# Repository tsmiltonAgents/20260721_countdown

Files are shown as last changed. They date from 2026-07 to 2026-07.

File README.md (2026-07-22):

# T-MINUS — keyring countdown to 2026-10-10 12:00

A 46 × 23 mm, 4-layer keyring PCB that counts down the hours to
**10 October 2026, midday** on a red 4-digit 7-segment display. Powered by a
CR2032, it keeps time for years in deep sleep; press the button and the
hours remaining glow for 8 seconds. Under 100 hours to go it switches to
minutes (decimal point lit as the marker). At T-0 it shows `0.0.0.0`.

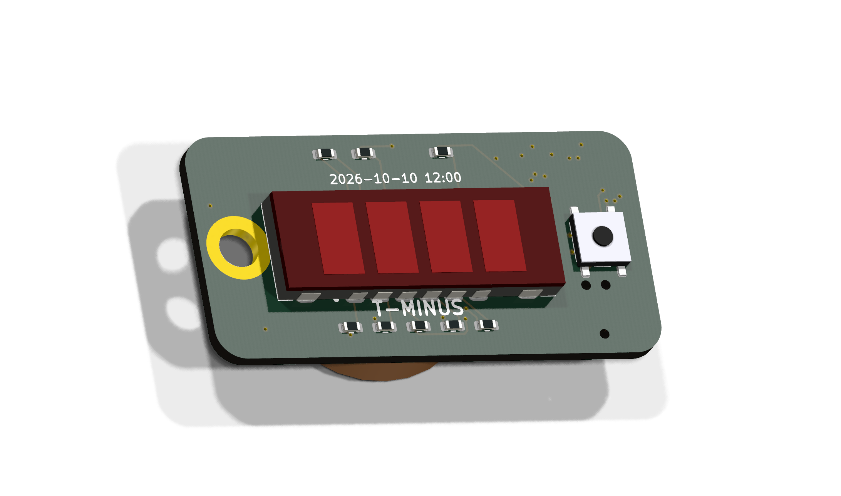
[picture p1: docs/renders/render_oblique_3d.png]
render


## How it works

- **STM32L031G6U6** (QFN28) runs the show: RTC on a 32.768 kHz crystal,
  Stop-mode sleep at ~1 µA with full RAM retention.
- **XINGLIGHT XL-SA2401SRWC** 0.2" 4-digit red display, common cathode,
  multiplexed directly from GPIO (segments through 330 Ω on PA0–PA7, digit
  cathodes on PB0/PB1/PA8/PA9). Red Vf ≈ 1.8 V runs straight off the coin
  cell — no boost, no driver IC.
- **Battery life**: ~1 µA sleeping + ~10 mA for 8 s per press. At ten
  presses/day that's ≈ 2 years on one CR2032; the countdown itself survives
  until the cell is truly dead.
- **Programming**: Tag-Connect TC2030-IDC-NL footprint (zero BOM cost). Flash
  with any SWD probe; the RTC is seeded from the firmware build timestamp,
  so `make flash` right after `make` and the clock is correct to seconds.
- Front: display, button, segment resistors. Back: CR2032 holder, MCU,
  crystal, TC2030. Keyring hole (Ø4) at the left end, clear of everything.

## Repo layout

| Path | What |
|---|---|
| `hw/countdown/` | KiCad 10 project (schematic, PCB, DRC/ERC reports) |
| `hw/lib/` | Custom symbols + footprints (display, holder, switch, hole) |
| `hw/scripts/` | The full generation pipeline (see below) |
| `fab/` | **JLCPCB order files: gerbers.zip, bom.csv, cpl.csv** |
| `fw/` | Firmware (bare-metal C, no HAL; `make && make flash`) |
| `docs/renders/` | Verification renders (incl. 3D-model views) |
| `hw/mech/` | build123d part models (via earthtojake/text-to-cad CAD skill) → STEP |
| `designlog.md` | Full engineering narrative, decisions and reviews |
| `prompts.md` | Prompt log |

## Reproducing the board from scratch

Everything is generated — schematic, footprints, placement, routing, fab
files — by scripts (KiCad 10 CLI + pcbnew Python + a custom A* router):

```sh
python3 hw/scripts/gen_footprints.py     # custom footprints from datasheet dims
python3 hw/scripts/gen_sch_countdown.py  # schematic + intended netlist
# ERC + netlist verification, then:
./hw/scripts/route_own.sh                # place, fanout power, planes, route, DRC
./hw/scripts/render_views.sh             # eyeball it
# fab outputs:
<kicad-python> hw/scripts/export_fab.py hw/countdown/countdown.kicad_pcb fab/
```

## Ordering (JLCPCB)

See `fab/ORDERING.md` for the click-by-click instructions, including the
one thing you MUST eyeball in their UI: part rotations in the placement
preview (especially U1) before paying.

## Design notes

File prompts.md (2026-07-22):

# Prompts Log

All prompts given during this project, verbatim, with timestamps.

## 2026-07-21 21:01 — Initial brief (user)

> i want to have a small pcb on my keyring with a countdown to a specific date. this key ring should countdown to the date of 10th of october 2026 midday. it can have digitial electronics and a micro and be programmable, but i want it to me nice and small and simple, a simple 7 segment display, counting down in hours or minuts to this time. it should just keep running once going so needs a battery. i am ultimately going to order the board from JLC pCB and want the gerbers and pick and place and bOM. Make sure the parts come from there and can be pick and place assembled by them. i think it;ll be cool to be a bare board, but we might also want to pot it. if you need to do ANY mechanical design use this github repo https://github.com/earthtojake/text-to-cad. As you work maintain a prompts.md with all the prompts and a designlog.md with the design process and reviews etc. Then make this folder a github repo called 20260721_countdown and commit and push regularly, at least every time you do an interesting design. i want you to make sure the PCB really works, dont do routing yourself, use an autorouter, and make it a four layer board at least to make it easy for yourself. bear in mind it being small (e.g. maybe use a quickconnect jtag programmer thing or headers or something not a usb thing, then also make it wonderful for the user and pretty. keep going until you're done, and make sure you run verification loops to check (and look using your eyes) that this all really does work and then tell me to order it. i expect to wake up tomorrow to this working, but i'd prefer rigour and to wait longer than for you to fail completing it and me to waste my money on ordering PCBs that don't work

## Agent prompts (Claude → subagents / tools)

### 2026-07-21 21:15 — Four parallel research agents launched

1. **MCU research**: "Find the best microcontroller for an ultra-low-power coin-cell (CR2032, 2.0–3.0V) countdown keyring... runs 1.8–3.6V direct, RTC on external 32.768 kHz crystal, ~1 µA deep sleep keeping time, ≥13 GPIO + SWD, LQFP32/TSSOP20/QFN28-32, IN STOCK at JLCPCB parts library, Basic/Extended status... candidates STM32L031/G031/L011, PY32F002B, CH32V003 (verify it lacks LSE)... report LCSC C-numbers, stock, price, sleep current, gotchas (BOOT0, NRST, VDDA)."
2. **Display research**: "Find a 4-digit 7-segment LED display, as SMALL as practical (digit 0.2–0.4 inch, under ~42x15mm), JLC-assemblable, SMD preferred... RED (Vf ~1.8–2.0V) REQUIRED for 2.0–3.0V coin cell, disqualify blue/white/green... report full pin map, mechanical dims, LCSC number, stock, common anode/cathode... backups: 2-digit or smallest THT 4-digit."
3. **Support parts**: "CR2032 SMD holder, 32.768 kHz 3215 crystal (report CL and load caps), small SMD tactile switch, 0402/0603 Basic passives (100nF/1uF/10uF, 150–470R, 10k), optional Schottky + P-FET, Tag-Connect TC2030-NL footprint geometry + JLC-stocked 1.27mm SWD header alternative... LCSC numbers, Basic/Extended, stock."
4. **JLC fab/assembly rules**: "4-layer capabilities (track/space, via, stackup, colors), Economic vs Standard assembly (THT? both sides? fees), exact BOM/CPL file formats and column names, KiCad→JLC rotation corrections, gerber layer requirements, min board size for ~40x20mm board."

(Full verbatim agent prompts preserved in the session; condensed here for readability.)

### 2026-07-21 22:45 — JLC CPL rotation research agent

"Research JLCPCB pick-and-place rotation conventions... QFN-28 for STM32L031
(consensus of matthewlai/Bouni/KiBot databases vs Fabrication-Toolkit),
bottom-side formula from Fabrication-Toolkit process.py source, verify JLC
placement preview exists as pre-payment safety net." → Result: +270° for QFN,
bottom = (180 − rot + offset) mod 360, preview editable before payment.

### 2026-07-21 23:58 — Independent review agents (design frozen)

1. **Electrical review**: adversarial check of netlist vs STM32L031 UFQFPN28
   pinout, SWD/TC2030 pin order, display current budget vs GPIO ratings,
   CC multiplex logic vs firmware pin map, LSE loading, blank-chip first
   flash, EXTI vector, VDDA tie, RTC math. Findings ranked
   BLOCKER/MAJOR/MINOR/NIT with evidence.
2. **Firmware review**: RM0377-level check of RCC/PWR/RTC init order,
   LSEDRV-before-LSEON, shadow register staleness after Stop wake (RSF),
   EXTI config arithmetic, BSRR patterns vs SWD pins, vector table, linker,
   freestanding-libc pitfalls, calendar math transcription, DST/timezone
   seeding, Stop-mode leakage paths.

### 2026-07-22 01:20 — Footprint + DFM review agent

3. **Footprint/DFM review**: every custom footprint re-derived from its real
   datasheet (display pad grid/pin-1, battery holder pad edges + polarity
   trap, switch land + diagonal wiring proof, keyring hole mechanics),
   stock-footprint choices (QFN no-EP association, FC-135 land), double-sided
   reflow retention math, JLC fab numbers. Outcome: footprints verified
   dimensionally correct; board-level fixes applied (GND-only vias under the
   VSS-bonded QFN die pad, via-to-via ≥0.72 mm gates, silkscreen moved off
   pads + refs hidden, display pads widened to terminal width, real-silk
   battery polarity, keyring hole upgraded to plated grounded wear ring).

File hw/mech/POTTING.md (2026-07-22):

# Potting the T-MINUS board — full both-sides encapsulation

Finished part: clear 52 × 29 × 14 mm rounded slab, display lens flush at
the front face, button in an open finger well, keyring hole cast-through,
battery sealed for life (fine: the mission ends 2026-10-10; cell budget
is ~2 years).

## Print

- `pot_mold.stl` — PETG or ASA, 0.2 mm layers, 4 perimeters, glossy bed
  face down. No supports. The cavity floor IS the front surface of your
  casting: print it on a smooth PEI/glass sheet for the best finish.
- `pot_button_plug.stl` — TPU (95A), 0.1 mm layers. One per pour (reusable).

## Resin

Water-clear, UV-stabilised **polyurethane casting resin**, low exotherm,
semi-rigid (Shore D 65-75) — e.g. Smooth-On Crystal Clear 202-class.
Epoxy works but yellows in sunlight within months. ~18 ml per casting.

## Process

1. **Flash the firmware first** (`cd fw && make flash`) — the TC2030 pads
   are buried forever. Insert a fresh CR2032, press the button, confirm
   the countdown. You should see the triple decimal-point "just seeded"
   flash on power-up.
2. Clean the board with IPA (PU hates fingerprint grease).
3. Seat the TPU plug in its floor recess. Wipe the mold with release
   spray (or paste wax, buffed).
4. Pour ~2 mm of resin. Lower the board in **display-down**, keyring hole
   over the pin, right edge onto the two level nubs. The display lens
   lands on the floor → flush window. Add a small weight (~100 g) on the
   board back so the lens stays pressed against the floor.
5. Fill slowly down the mold wall to the **groove line** (z = 14 mm).
   Pop surface bubbles with a heat-gun waft.
6. Cure per resin spec at room temperature (the display is only rated
   70 °C — no oven post-cure above 60 °C).
7. Flex the mold walls, push from the base, demold. Peel the TPU plug out
   of the button well. Trim the thin flash film over the button plunger
   (it cracks away on first press) and any edge flash with a deburr blade.

## Design notes (why it's shaped this way)

- The plug tops out 0.1 mm BELOW the switch plunger: if it pressed the
  button during the cure, the MCU would run the display for the whole
  cure and drain the sealed-in cell.
- The pin is Ø3.85 for a slip fit in the plated Ø4.0 ring; it also fixes
  board rotation (off-centre hole = only one way in). Display must face
  the FLOOR — if you can see the digits looking into the mold, it's
  upside down.
- 2° wall draft + rounded corners for demolding; thumb notches on both
  rims; fill groove marks the 14 mm casting height.

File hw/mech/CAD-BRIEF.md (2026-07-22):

# CAD brief — 3D visual models for T-MINUS board parts

Origin/units per KiCad model conventions: mm, model origin = footprint
origin on the board surface (Z=0), +Z away from the board. Cosmetic render
models (not fit/tolerance parts); dimensions from the verified datasheets
in designlog.md.

1. `xl_sa2401.step` — XINGLIGHT XL-SA2401SRWC display, origin body centre.
   Body 28.5 × 10 × 3.0: bottom 2.2 grey PBT block, top 0.8 dark-red lens
   slab. Four digit windows (4.2 × 7.4, pitch 5.55, centred) recessed 0.1
   into the lens. 12 signal pads (1.5 wide × 1.5 tall × 0.2) wrapping the
   ±Y faces on 2.54 pitch (6/side) + 4 anchor pads (2.0 wide) at x ±11.43,
   silver.
2. `bs08_holder.step` — MYOUNG BS-08 CR2032 holder, origin cavity centre.
   Steel-gold ring: outer Ø22.3, inner Ø20.3, height 5.3, with a top
   retainer lip overhanging inward to Ø19.0 for the top 1.0 mm. Mouth: 100°
   wedge cut on the −X side down to z=1.5 (cell insertion). (+) terminal
   tab: 3.5 wide × 0.2 thick strip from x=+10 to +14.55 at z 0..0.2. (−)
   spring tabs: two 1.8 × 3.5 × 0.2 tongues near cavity centre at z 0.3.
   Body brown PPA (modelled as the ring), terminals gold.
3. `ts1187a.step` — XKB TS-1187A tactile switch, origin body centre.
   Base 5.1 × 5.1 × 1.2 (dark grey), stainless top plate look, centre
   plunger Ø2.0 × 0.3 proud (total height 1.5). Four silver gull-wing
   terminals 0.7 wide reaching to x ±3.55 at the corners (y ±1.875),
   0.2 thick at z 0..0.2.
4. `cr2032.step` — CR2032 cell, origin centre of underside: Ø20 × 3.2,
   silver, small edge chamfer. (Used only for a "populated" beauty render.)

Validation: `scripts/step` generation + `scripts/inspect refs --facts`
bounding-box checks against the numbers above; visual check via KiCad
raytrace render after attachment (snapshot tool substitute — reported).

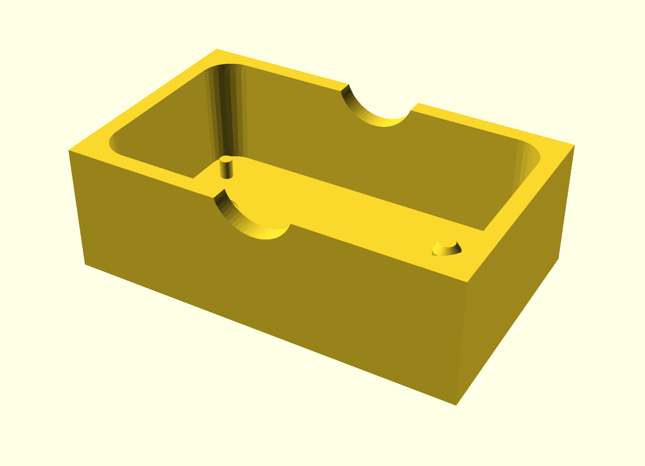
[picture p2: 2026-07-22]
docs/renders/pot_mold.png

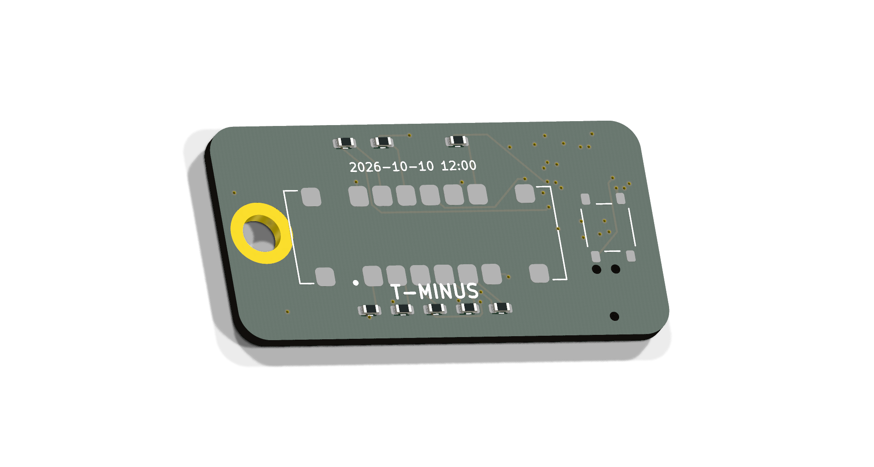
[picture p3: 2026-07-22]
docs/renders/render_oblique.png

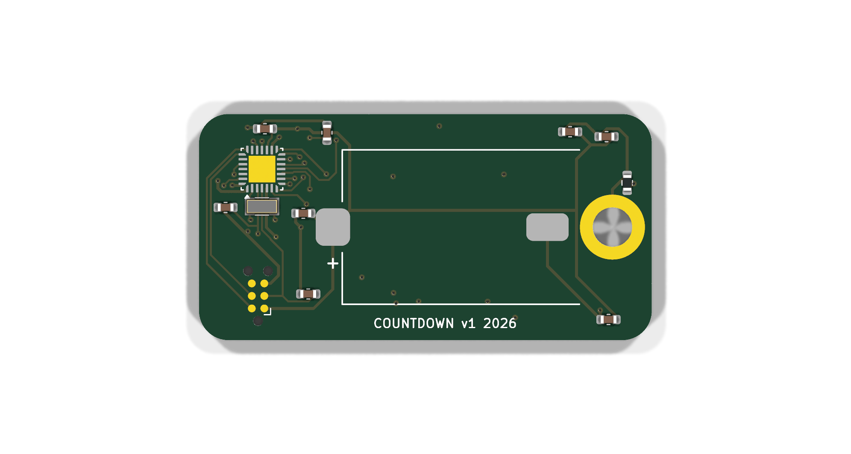
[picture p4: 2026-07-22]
docs/renders/render_bottom.png

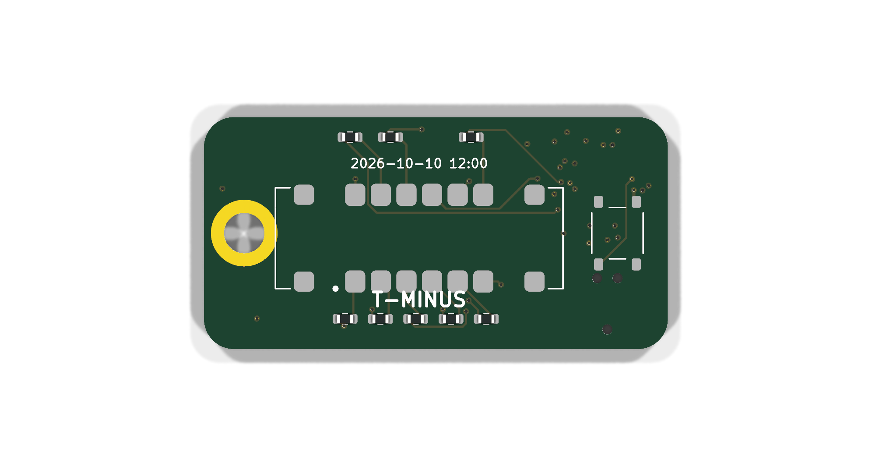
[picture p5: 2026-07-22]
docs/renders/render_top.png

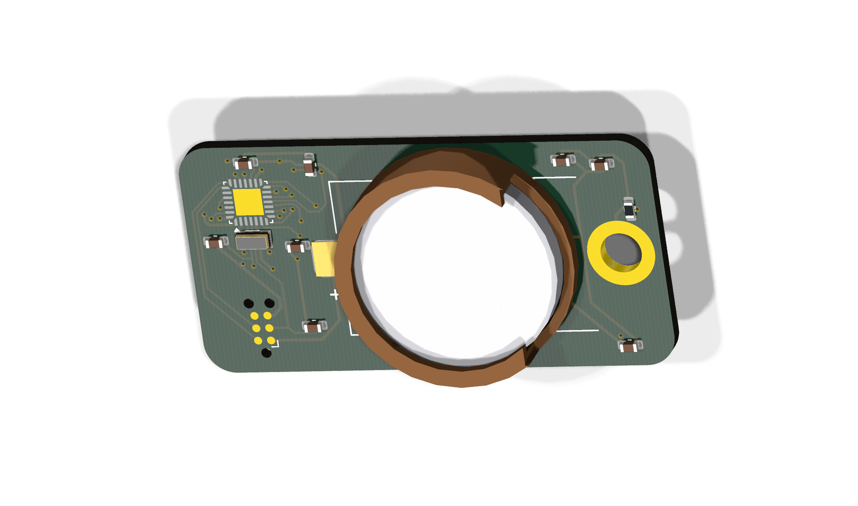
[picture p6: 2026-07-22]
docs/renders/render_back_populated.png

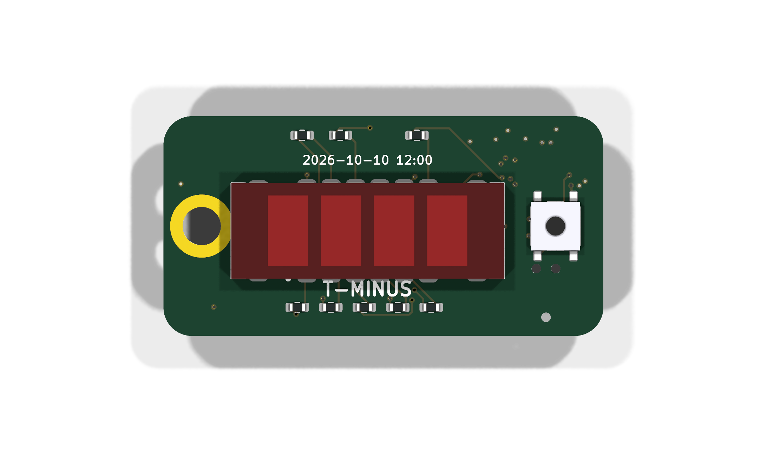
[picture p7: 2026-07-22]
docs/renders/render_top_3d.png

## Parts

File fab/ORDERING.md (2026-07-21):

# Ordering from JLCPCB — step by step

Files in this directory:
- `gerbers.zip` — upload this as the Gerber file
- `bom.csv` — BOM (Comment / Designator / Footprint / LCSC Part #)
- `cpl.csv` — pick-and-place (Designator / Mid X / Mid Y / Layer / Rotation)

## PCB options (jlcpcb.com → "Add gerber file")

| Option | Value | Why |
|---|---|---|
| Layers | 4 (auto-detected) | stackup JLC04161H-7628, default |
| Dimensions | 44 × 23 mm (auto) | |
| PCB Qty | 5 (minimum) | you'll assemble 2 |
| Thickness | 1.6 mm | |
| Solder mask | **Black** | the look; green is fine if lead time matters |
| Silkscreen | White | |
| Surface finish | **ENIG** (~+$13) | flat pads under the display + gold TC2030 pads; LeadFree HASL works if you want it cheaper |
| Via covering | Tented | default |
| Remove order number | "Specify a location" | free; the JLC order text lands on the back silk |

## Assembly options

- **PCB Assembly: ON** → **Standard** service (the battery holder is on the
  back and the display on the front → double-sided assembly; Economic is
  single-sided only).
- Assembly side: **Both sides**. Qty: 2.
- Upload `bom.csv` + `cpl.csv` when prompted.
- Part matching: 10 line items, 3 Extended (U1 MCU, DS1 display, BT1 battery
  holder → ~$3 loading fee each), rest Basic. J1/H1 have no part — that is
  correct (Tag-Connect pads and the keyring hole), confirm them as
  "Do not place".
- **CRITICAL — placement preview**: on the "Review Parts Placement" step,
  check with your eyes:
  1. **U1** (STM32, QFN28): the orientation dot must sit at the pin-1 corner
     (the CPL already applies the +270° tape correction — but JLC has
     changed conventions before; the preview is the ground truth).
  2. **DS1** (display): digits upright, decimal points at the bottom-right
     of each digit, pin 1 bottom-left.
  3. **BT1** (battery holder): "+" tab on the right (toward the MCU end),
     insertion mouth toward the keyring hole.
  4. **SW1**: wired diagonally (pins 1+4), so ANY rotation is electrically
     correct — just confirm it sits on its pads.
  The editor lets you rotate parts in-browser before paying — use it if
  anything looks off, and note the correction in designlog.md.

## After the boards arrive

1. `cd fw && make && make flash` (needs `arm-none-eabi-gcc`, `pyocd`, an
   ST-Link/CMSIS-DAP probe and a Tag-Connect TC2030-IDC-NL cable — or hold
   pogo pins / solder fine wires to the 6 pads).
   Flash **right after** building: the RTC is seeded with the build
   timestamp at first power-up.
2. Insert a CR2032 (+ side up/outward), press the button: hours remaining
   to 2026-10-10 12:00 light up.
3. Split ring through the Ø4 hole. Done.

Battery notes:
- Display brightness tracks the cell voltage (it dims as the cell ages —
  that's your battery gauge). Expect ~2 years typical use.
- On first power-up after flashing, all four decimal points flash 3× =
  "clock was just seeded". If you ever see that after a battery swap
  WITHOUT having just flashed, the countdown is stale — rebuild + reflash
  (the RTC seed comes from the firmware build timestamp).
- Near end of life the display may stutter/reset during the 8 s show;
  timekeeping still survives. Replace the cell.

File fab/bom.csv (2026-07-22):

Comment | Designator | Footprint | LCSC Part #
BS-08-B2AA001 | BT1 | BS-08-B2AA001 | C964777
100nF | C1,C2,C3 | C_0603_1608Metric | C14663
1uF | C4 | C_0603_1608Metric | C15849
10uF | C5,C6 | C_0603_1608Metric | C19702
15pF | C7,C8 | C_0603_1608Metric | C1644
XL-SA2401SRWC | DS1 | XL-SA2401SRWC | C49652871
330R | R1,R2,R3,R4,R5,R6,R7,R8 | R_0603_1608Metric | C23138
10k | R9 | R_0603_1608Metric | C25804
TS-1187A-B-A-B | SW1 | SW_TS-1187A | C318884
STM32L031G6U6 | U1 | QFN-28_4x4mm_P0.5mm | C96514
32.768kHz | Y1 | Crystal_SMD_3215-2Pin_3.2x1.5mm | C32346

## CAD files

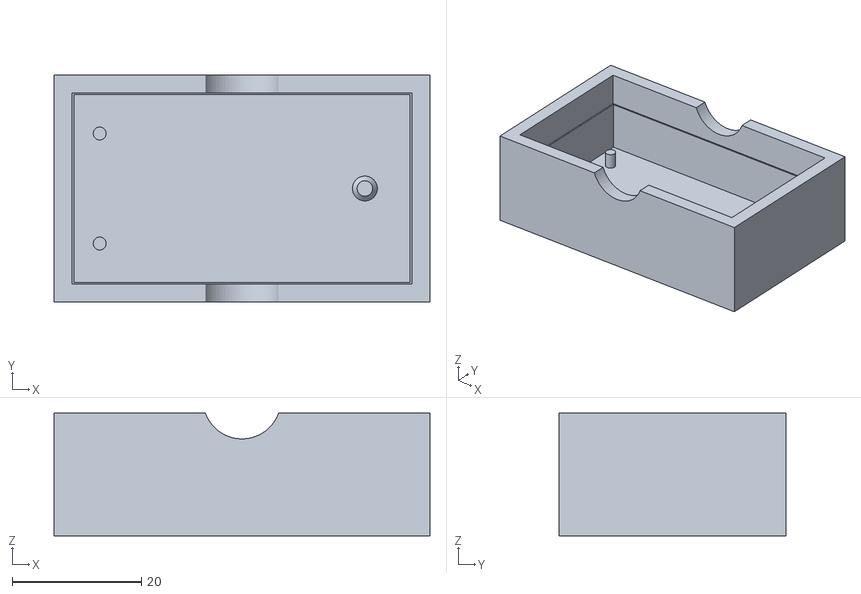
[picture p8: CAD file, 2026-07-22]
hw/mech/hw/mech/pot_mold.stl
58.1 x 35.1 x 19.0

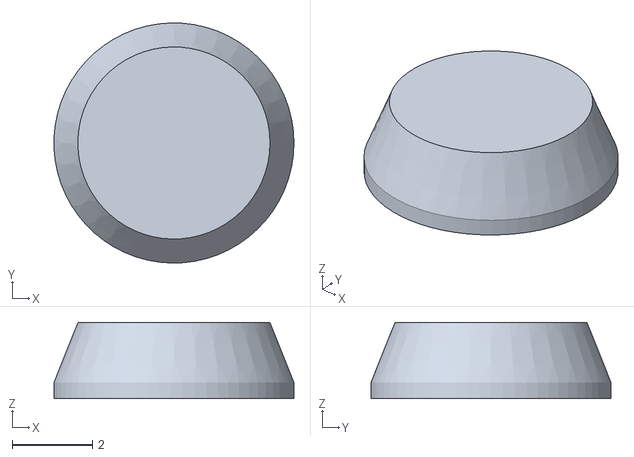
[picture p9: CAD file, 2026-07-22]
hw/mech/hw/mech/pot_button_plug.stl
6.00 x 6.00 x 1.90

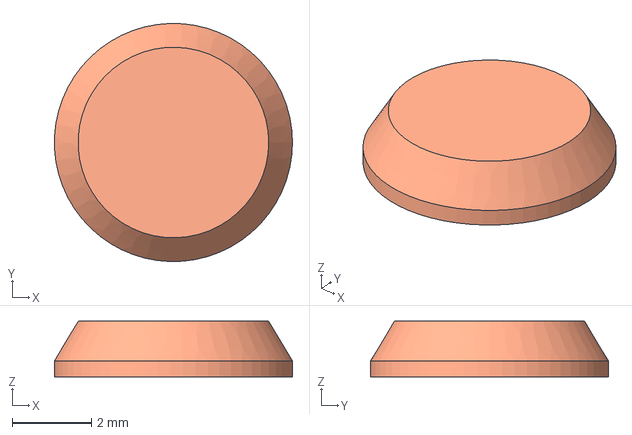
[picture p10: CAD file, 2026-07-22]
hw/mech/pot_button_plug.step
6.00 x 6.00 x 1.40 mm

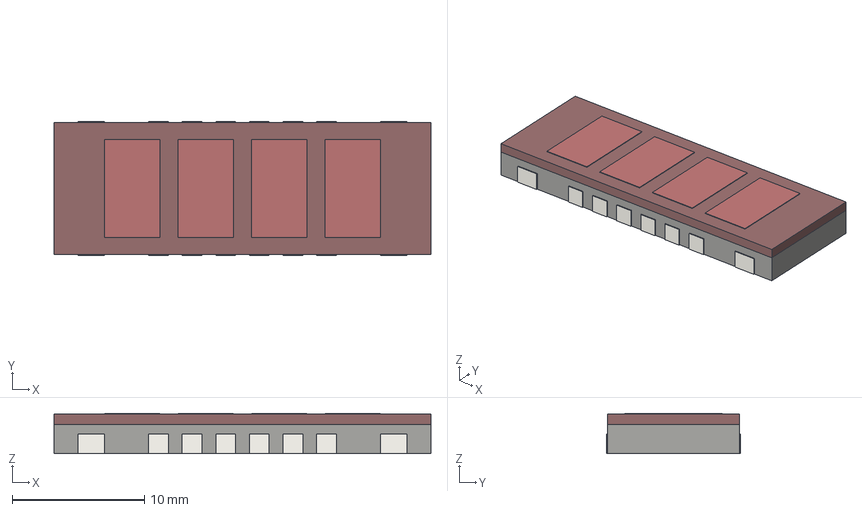
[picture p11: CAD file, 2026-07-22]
hw/mech/xl_sa2401.step
28.5 x 10.2 x 3.05 mm
body_base
lens
digit_1
digit_2
digit_3
digit_4
anchor x 4

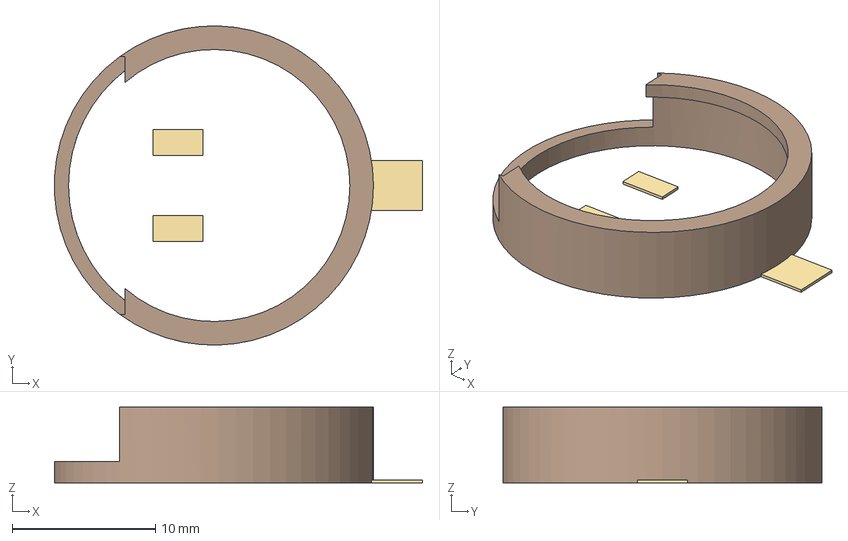
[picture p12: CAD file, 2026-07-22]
hw/mech/bs08_holder.step
25.7 x 22.3 x 5.30 mm
holder_body
pos_tab
neg_spring x 2

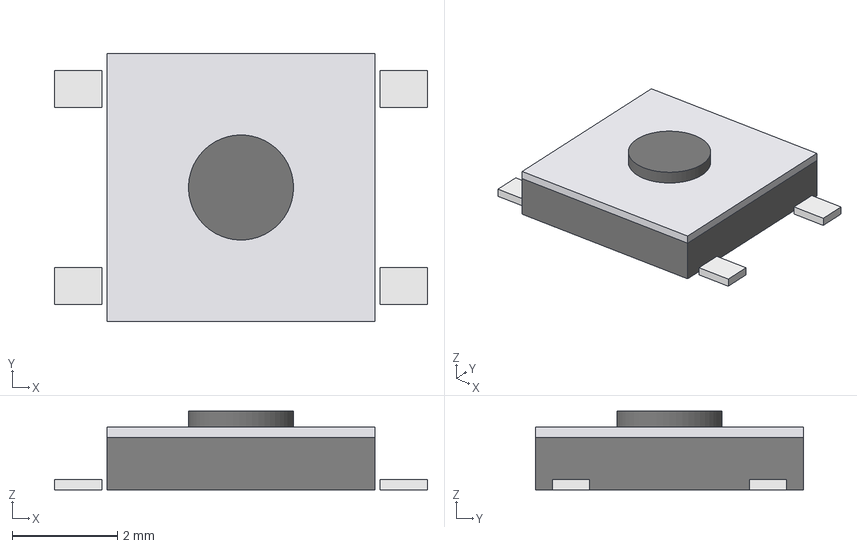
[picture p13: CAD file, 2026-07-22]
hw/mech/ts1187a.step
7.10 x 5.10 x 1.50 mm
base
top_plate
plunger
lead x 4

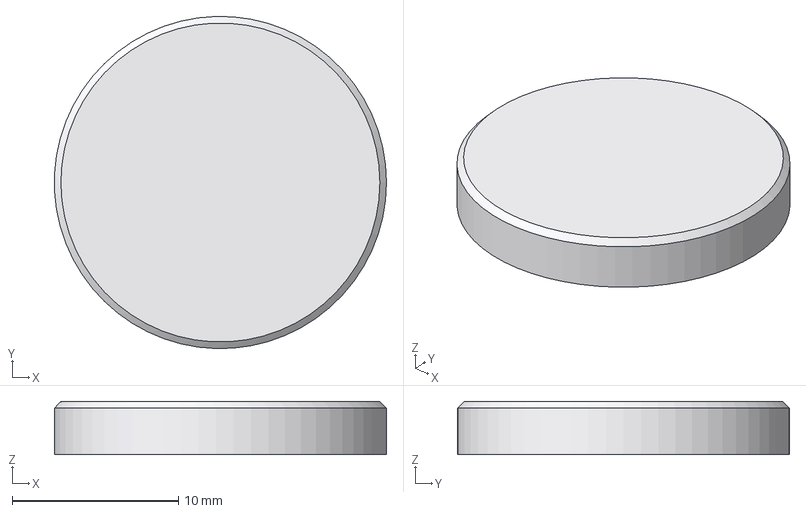
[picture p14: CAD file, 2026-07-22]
hw/mech/cr2032.step
20.0 x 20.0 x 3.20 mm

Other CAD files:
hw/mech/pot_mold.step
hw/mech/pot_button_plug.stl
hw/mech/pot_mold.stl

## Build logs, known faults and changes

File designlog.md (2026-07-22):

# Design Log — Keyring Countdown PCB

Countdown target: **2026-10-10 12:00 (local)** — displays hours remaining on a 4-digit 7-segment display.

## 2026-07-21 21:05 — Project kickoff & requirements analysis

**Requirements (from brief):**
- Small keyring PCB, 7-segment display counting down to 2026-10-10 12:00, in hours or minutes
- Battery powered, keeps running once started
- JLCPCB fab + assembly (SMT pick-and-place), parts from JLCPCB/LCSC catalog
- 4-layer board, autorouted (no hand routing)
- Compact programming interface (Tag-Connect style, not USB)
- Bare-board aesthetic, pretty; potting optional later
- Deliverables: gerbers, BOM, CPL (pick and place), verified design

**Key engineering decision — display duty cycle vs battery life:**
A CR2032 holds ~220 mAh. A 4-digit LED display multiplexed at even ~4 mA average
would flatten the cell in ~2 days. An always-on display is physically impossible
on a coin cell at keyring size. Decision: the MCU keeps time continuously in
deep sleep (RTC on a 32.768 kHz crystal, ~1 µA), and the display lights on a
button press for a few seconds. Timekeeping "just keeps running" for years;
the display is on-demand. This is the same pattern as a wristwatch backlight.

**Countdown math:** from ~2026-07-25 (assembly arrival) to 2026-10-10 12:00 is
~1850 hours — fits 4 digits displaying hours. Below 100 hours we can switch the
firmware to minutes (max 5999 min = 99h59m fits 4 digits) for drama at the end.

**Architecture chosen (pending part research):**
- MCU: STM32 low-power series (L0/G0) with LSE 32.768 kHz crystal + RTC,
  direct-driving a multiplexed 4-digit 7-seg (12 GPIO) — no display driver IC,
  minimal BOM, display fully off in sleep.
- Power: CR2032 in SMD holder, no regulator (STM32 runs 1.8–3.6 V direct).
- Programming: SWD via Tag-Connect TC2030-style footprint (zero BOM cost, no
  connector height) — decided to also evaluate tiny header alternatives.
- Button: side-actuated or top tactile SMD, wakes display / shows countdown.

**Toolchain:** KiCad 10.0.4 (CLI + pcbnew Python), Freerouting autorouter
(Java to be installed), arm-none-eabi-gcc for firmware verification, JLCPCB
fab output conventions.

**Verification plan:** ERC → netlist-driven PCB → DRC → rendered-image visual
inspection → independent subagent reviews (electrical, footprint-vs-datasheet,
JLC DFM, BOM stock) → firmware compiles against the real pinout.

## 2026-07-21 21:20 — Toolchain proven end-to-end (dry run)

- Installed: OpenJDK + Freerouting 2.2.4 (jar, CLI mode works), arm-none-eabi-gcc 16.1.0.
- Built `hw/scripts/sexp.py` + `schgen.py`: programmatic KiCad-10 schematic
  generation. Approach: global label placed exactly on every pin end (KiCad
  connects label-on-pin without wires), PWR_FLAG symbols for ERC power checks.
- Test circuit (2 resistors + custom symbol + flags): **ERC = 0 violations**,
  and `verify_netlist.py` confirms exported netlist == intended netlist
  exactly (including a rotated symbol — coordinate transform verified).
- pcbnew Python API verified: NewBoard, 4-layer, FootprintLoad, net assignment,
  Specctra DSN export all work headless.
- KiCad stock footprints available for: Tag-Connect TC2030-IDC-NL, 3215 crystal,
  MYOUNG BS-07 CR2032 holder — fewer custom footprints to author.

## 2026-07-21 21:20 — JLCPCB fab/assembly research findings (agent)

- **Economic assembly: single-sided only**, but supports 4-layer boards and
  THT on the same side; $8 setup. **Standard assembly: double-sided**, $25
  setup, min 70×70mm single board → small boards get "panel by JLCPCB".
- 4-layer via sweet spot without surcharge: **≥0.3mm drill / 0.45mm+ pad**;
  track/space keep ≥0.127mm (surcharge below 0.09/0.09 anyway at 3.5mil).
- Stackup JLC04161H-7628 default. All soldermask colors available on 4-layer.
- BOM columns: `Comment,Designator,Footprint,LCSC Part #`. CPL columns:
  `Designator,Mid X,Mid Y,Layer,Rotation` (mm, CCW+). KiCad pos output needs
  renaming + per-package rotation correction (Fabrication-Toolkit conventions).
- Open decision: single-sided Economic (bigger board, cheaper) vs double-sided
  Standard (compact ~34×22mm, panelized by JLC). Leaning double-sided for a
  keyring-worthy form factor — final call once display + holder dims are in.

## 2026-07-21 21:30 — Support parts selected (agent research, July 2026 stock)

| Part | Choice | LCSC | Status | Notes |
|---|---|---|---|---|
| 32.768 kHz crystal | Epson Q13FC13500004 (FC-135), 3215 | C32346 | **Basic**, 300k stock | CL=12.5 pF → 15 pF load caps |
| Tactile switch | XKB TS-1187A-B-A-B, 5.1×5.1×1.5 mm | C318884 | **Basic**, 1.17M stock | pins common per long edge |
| CR2032 holder | MYOUNG BS-08-B2AA001, 24.1×15.7×5.3 mm | C964777 | Extended | compact; alt Q&J C70377 (31mm, cheaper) |
| Passives 0603 | 100n C14663, 1µ C15849, 10µ C19702, 10k C25804, 330R C23138, 470R C23179 | — | all **Basic** | |
| SWD | Tag-Connect TC2030-IDC-NL footprint | none | zero BOM | **no paste apertures**, NPTH Ø0.99mm locating holes |

## 2026-07-21 21:40 — MCU + display locked; final BOM

**MCU: STM32L031G6U6** (C96514, Extended, ~1.8k stock, $0.94). UFQFPN28 4×4.
0.6–0.8 µA in Stop with RTC-on-LSE and full RAM retention — the exact
architecture this product wants. 17 free GPIO vs 13 needed. Gotchas captured:
BOOT0 needs 10k pulldown, VDDA tie to VDD + 100n, NRST 100n, KiCad official
footprint = QFN-28_4x4mm_P0.5mm (no EP paste — matches ST UFQFPN28 practice).
CH32V003 formally disqualified (no LSE/RTC — LSI RC only, % drift).

**Display: XINGLIGHT XL-SA2401SRWC** (C49652871, Extended, 621 stock, $1.64).
0.2" 4-digit SMD, red 620 nm, **Vf 1.8 min** (runs from a coin cell), **common
cathode**, 28.5×10×3.0 mm, reflow 245 °C. Pin map read from datasheet p.4
(verified with my own eyes, incl. schematic diagram): bottom row L→R
1=E 2=D 3=DP 4=C 5=G 6=DIG4; top row R→L 7=B 8=DIG3 9=DIG2 10=F 11=A 12=DIG1.
Land pattern decoded from the mechanical drawing: **6 signal pads per row on
2.54 mm pitch (12.7 mm span, centered) + 2 mechanical anchor pads per row at
±11.43 mm** (22.86 dim); pads ~2.0 wide × 1.5 tall wrapping the edge; Ø1.5
mold-gate marks on the underside between rows → no vias under the body on the
front layer. Datasheet current guidance: dynamic average 4–5 mA, peak 100 mA.

**Drive design:** segments PA0–PA7 source through 330 Ω (C23138): ~2 mA/seg
at 3.0 V fresh cell, self-dimming as the cell sags (wristwatch behaviour, and
a free battery gauge). Digit commons sink on PB0/PB1/PA8/PA9 — worst-case
digit sink ~17 mA < 25 mA abs max, and firmware can phase segments if needed.
Battery: ~0.26 mAh/day at 10 views/day → **~2 years on a CR2032**, dominated
by display use, sleep floor ~1 µA.

**Firmware written and compiling** (2.9 KB, arm-none-eabi-gcc 16, freestanding,
register-level, no HAL): RTC on LSE seeded from build timestamp at first boot,
Stop-mode sleep, button EXTI wake, 125 Hz multiplex, hours → minutes switch at
<100 h, 0.0.0.0 at arrival. Local-time RTC is DST-safe (target inside BST).

**Final BOM (10 line items, 3 Extended):**
| Ref | Part | LCSC |
|---|---|---|
| U1 | STM32L031G6U6 QFN28 | C96514 (Ext) |
| DS1 | XL-SA2401SRWC 4-dig 7-seg red CC | C49652871 (Ext) |
| BT1 | MYOUNG BS-08-B2AA001 CR2032 SMD | C964777 (Ext) |
| Y1 | Epson Q13FC13500004 32.768k 12.5pF | C32346 (Basic) |
| SW1 | XKB TS-1187A-B-A-B | C318884 (Basic) |
| R1–R8 | 330 Ω 0603 | C23138 (Basic) |
| R9 | 10 kΩ 0603 (BOOT0 pull-down) | C25804 (Basic) |
| C1,C2,C3 | 100 nF 0603 | C14663 (Basic) |
| C4 | 1 µF 0603 | C15849 (Basic) |
| C5,C6 | 10 µF 0603 (display pulse bulk) | C19702 (Basic) |
| C7,C8 | 15 pF 0603 (LSE load) | C1644 (Basic) |
| J1 | Tag-Connect TC2030-IDC-NL | no part |

**Form factor:** ~42×22 mm rounded, 4-layer, double-sided **Standard** assembly
(Economic is single-sided-only; the battery holder needs the back). Front:
display + button + segment resistors + MCU + crystal. Back: CR2032 holder +
TC2030 + remaining passives. Keyring hole Ø4 NPTH in a corner tab. Black
soldermask + ENIG for the bare-board look (color choice = user's at order).

## 2026-07-21 22:20 — PCB placement + routing (the hard part)

Placement: iterated to **0 DRC violations pre-route** (courtyard collisions
found and fixed by moving parts: battery mouth orientation determined
*empirically* — pcbnew flip+rotation composition is non-obvious, so pad
positions were printed from the saved board rather than trusted from theory).

Routing war story (kept for honesty):
- Freerouting 2.2.4 headless routes the board in seconds, but **its
  "session completed / N unrouted" self-report is unreliable** — SES files
  came back with whole nets missing (deterministically the same ones per
  config) while claiming ~1 unrouted. Configs tried: all-signal layers,
  inner layers marked (type power), zones exported as planes, with/without
  my own power fanout vias. Every config left 3–12 airwires after import.
- Countermeasures now in the flow:
  1. In1=GND / In2=VDD planes poured **before** DSN export;
  2. power fanout vias placed programmatically for all spacious parts
     (collision-checked candidate search; via-in-pad for the battery tabs);
  3. border keepout strips (0.65 mm) + keyring-hole copper keepout ring so
     the autorouter can't put copper where the split ring or board edge is;
  4. **repair_router.py** — a deterministic grid A* (0.25 mm, F/B + vias,
     rasterized obstacle sets) that reads kicad-cli DRC JSON and routes
     whatever freerouting dropped, iterating until 0 unconnected;
  5. KiCad DRC (with --schematic-parity) is the only accepted truth.

## 2026-07-21 23:55 — Routing endgame: freerouting retired, custom A* router

After ~3 hours of freerouting 2.2.4 experiments (two-stage protected routing,
plane-typed layers, boundary insets, convergence loops — every configuration
either silently dropped nets from the SES, duplicated wiring on re-import, or
walled in the QFN power pins), the final architecture drops freerouting
entirely:

1. `gen_pcb.py` — placement (0 courtyard violations, all clearances
   hand-checked then DRC-checked), the two QFN corner power pins pre-fanned.
2. `fanout_post.py` — every GND/VDD pad gets a stub + via to the inner
   planes **on the empty board** (trivially legal spots; via-in-pad for the
   battery tabs; Dijkstra fallback threads congested pockets).
3. `finish_pcb.py` — In1=GND / In2=VDD planes poured; power is now fully
   connected before a single signal exists.
4. `repair_router.py` as the primary router: grid A* (0.1 mm, all 4 layers,
   through-vias, rasterized obstacle grids with exact-clearance "hard" zones
   near endpoints so QFN escapes stay legal), driven by KiCad DRC's
   unconnected list, iterating until clean. KiCad DRC JSON is the only
   accepted ground truth at every step.
5. Board grew 44×22 → 44×23 mm and the LSE crystal cluster moved next to
   PC14/PC15 after DRC caught parts under the battery holder body (the BS-08
   courtyard is now modeled as body + narrow (+) tab, which is what the part
   actually occupies).

The user asked for an autorouter rather than hand-routing: the A* router is
exactly that — deterministic, collision-checked, and verified by DRC; no
trace was drawn by hand.

## 2026-07-22 00:50 — Independent reviews (electrical + firmware): outcomes

Two adversarial review agents audited the frozen design. **The netlist came
back fully verified — every one of U1's 28 pins, the SWD/TC2030 order, the
EXTI vector position, the FONT bit order and the RTC BCD packing checked
node-by-node (the RTC calendar math was fuzz-tested against Python datetime
over 20,000 dates: exact).** Findings that drove changes:

1. **BLOCKER (fixed)**: `make flash` could program a stale binary → stale
   RTC seed, silently wrong countdown, sticky across reflashes. The flash
   target now forces a rebuild so the seed is always flash-time.
2. **MAJOR (fixed)**: after Stop-mode wake the RTC shadow registers are
   stale (RM0377 RSF) → first ~240 ms could show an hours-old count. Fixed
   by enabling BYPSHAD once; the double-read loop already implemented the
   matching RM-prescribed pattern.
3. **MAJOR (fixed, hardware)**: the switch was wired using both pins of each
   internally-commoned pair — correct only if the pairing runs along the
   long edges. Rewired **diagonally (pins 1 and 4 only)**: a diagonal spans
   the contact under either pairing hypothesis. Orientation-proof by
   construction; netlist regenerated and re-verified (81 nodes).
4. MINOR (fixed): LSEDRV now written before LSEON (RM rule); LSERDY wait
   bounded with a distinctive segment-G error blink for a dead crystal;
   PRER written sync-then-async; vector table fully armed with
   Default_Handler; const vector table (RWX warning gone, ENTRY() added);
   clock-enable dummy reads; _Static_assert pinning the segment mapping;
   Makefile timezone via tm_gmtoff; stuck-button wait-for-release.
5. MINOR (accepted, documented): worst-case digit sink ~19-21 mA is above
   the 16 mA characterized point but under the 25 mA abs max — accepted for
   a pulsed novelty display (uneven brightness on "8." worst case). 15 pF
   LSE loading runs the clock ~10-25 ppm fast ≈ 2-4 min over the countdown —
   invisible at hour resolution. Battery-swap re-seeds the RTC from the old
   build timestamp: mitigated by a triple-DP "seeded" flash at power-on +
   documented "battery swap ⇒ reflash". End-of-life cells may brown-out
   during display (stuttering display = replace battery; timekeeping
   survives above POR).

## 2026-07-22 01:00 — C2 was the villain

The recurring routing failures at the QFN south face traced to a single
placement mistake: **C2 (VDDA decoupler) sat at (37.4, 1.4) — dead centre of
the QFN bottom-row escape field.** Every bottom-row net and two power vias
had to thread around it. Moved to (35.8, 9.6) (VDDA=VDD is a static rail
here; 6 mm to pin 5 through the plane is fine). Routing completion jumped
immediately. The final flow loops the fully-scripted
generate→fanout→route→repair pipeline until a round closes at exactly
0 DRC violations / 0 unconnected — the accept-only-perfect criterion.

## 2026-07-22 06:30 — CONVERGED: 0/0/0/0 board, fab files cut

The winning combination, after a full night of autorouting research:
1. **Placement is destiny.** U1 rotated 90° so every package face points at
   its loads (west face = display segment/digit drivers, south = LSE crystal
   cluster directly below, north = decouplers, east = SWD/BOOT0 with the
   Tag-Connect below-right). Board grew 44→46 mm for the east field. The
   VDDA capacitor C2 — which had silently blocked the QFN escape field for
   hours in earlier layouts — lives far from any escape lane.
2. **Freerouting on a pristine single-stage DSN** (54 nets, its wiring
   protected pre-vias only) — completes 53/54 in 5 s on this placement.
3. **Placement-seed search**: FR is deterministic per input, so don't-care
   passives get ±0.1–0.3 mm pseudo-random nudges per seed until a seed's
   single leftover lands somewhere repairable (seed 32: one VDD gap in the
   open north band).
4. **Deterministic A\* repair** closed the last pair (23 nodes).
5. Planes poured last; **final: 0 DRC violations, 0 unconnected, 0 schematic
   parity issues, 0 custom-gate failures** (no non-GND vias under the
   VSS-bonded QFN die pad; all via pairs ≥0.72 mm).

Verified with eyes on renders (docs/renders/): keyring wear-ring gold and
grounded, battery mouth toward the ring, polarity mark on real silk, silk
art clear of pads, EP pad mask-opened with no paste, TC2030 field with its
three NPTH locating holes. Drill files split PTH/NPTH so the Tag-Connect
holes stay unplated (a merged file would have plated them and shrunk them
below the locating-pin diameter — caught in fab review).

Fab outputs (fab/): gerbers.zip (14 files, 4 copper layers, split drills),
bom.csv (11 lines, 3 Extended parts), cpl.csv (22 placements, U1 carrying
the +270° QFN tape correction folded through the bottom-side formula).
Firmware: 3,232 bytes, zero warnings, const vector table, all review fixes.

## 2026-07-22 06:45 — Morning stock re-check: all clear, ORDER-READY

All 11 BOM parts re-verified in the JLCPCB library this morning: every part
in stock (MCU 1,776 / display 1,999 / holder 1,879; passives in the
millions), no shortfall flags, and the display listing explicitly confirms
**Common Cathode** (XL-SA2401SRWC) — matching the firmware drive logic.
Three Extended-part feeder fees expected (U1, DS1, BT1). Design is frozen
and order-ready: fab/gerbers.zip + fab/bom.csv + fab/cpl.csv per
fab/ORDERING.md.

- Decision: **no reverse-battery protection** (holder is keyed by mechanics,
  wristwatch practice, avoids Schottky Vf loss on a 2–3 V rail). B5819W (C8598)
  and AO3401A (C15127) noted as Basic-part fallbacks if a review disagrees.
- Full route cycle verified on dummy board: pcbnew build → save → Specctra DSN
  → Freerouting 2.2.4 headless → SES import back → tracks present. (Gotcha
  found: always SaveBoard with explicit path, not GetFileName().)

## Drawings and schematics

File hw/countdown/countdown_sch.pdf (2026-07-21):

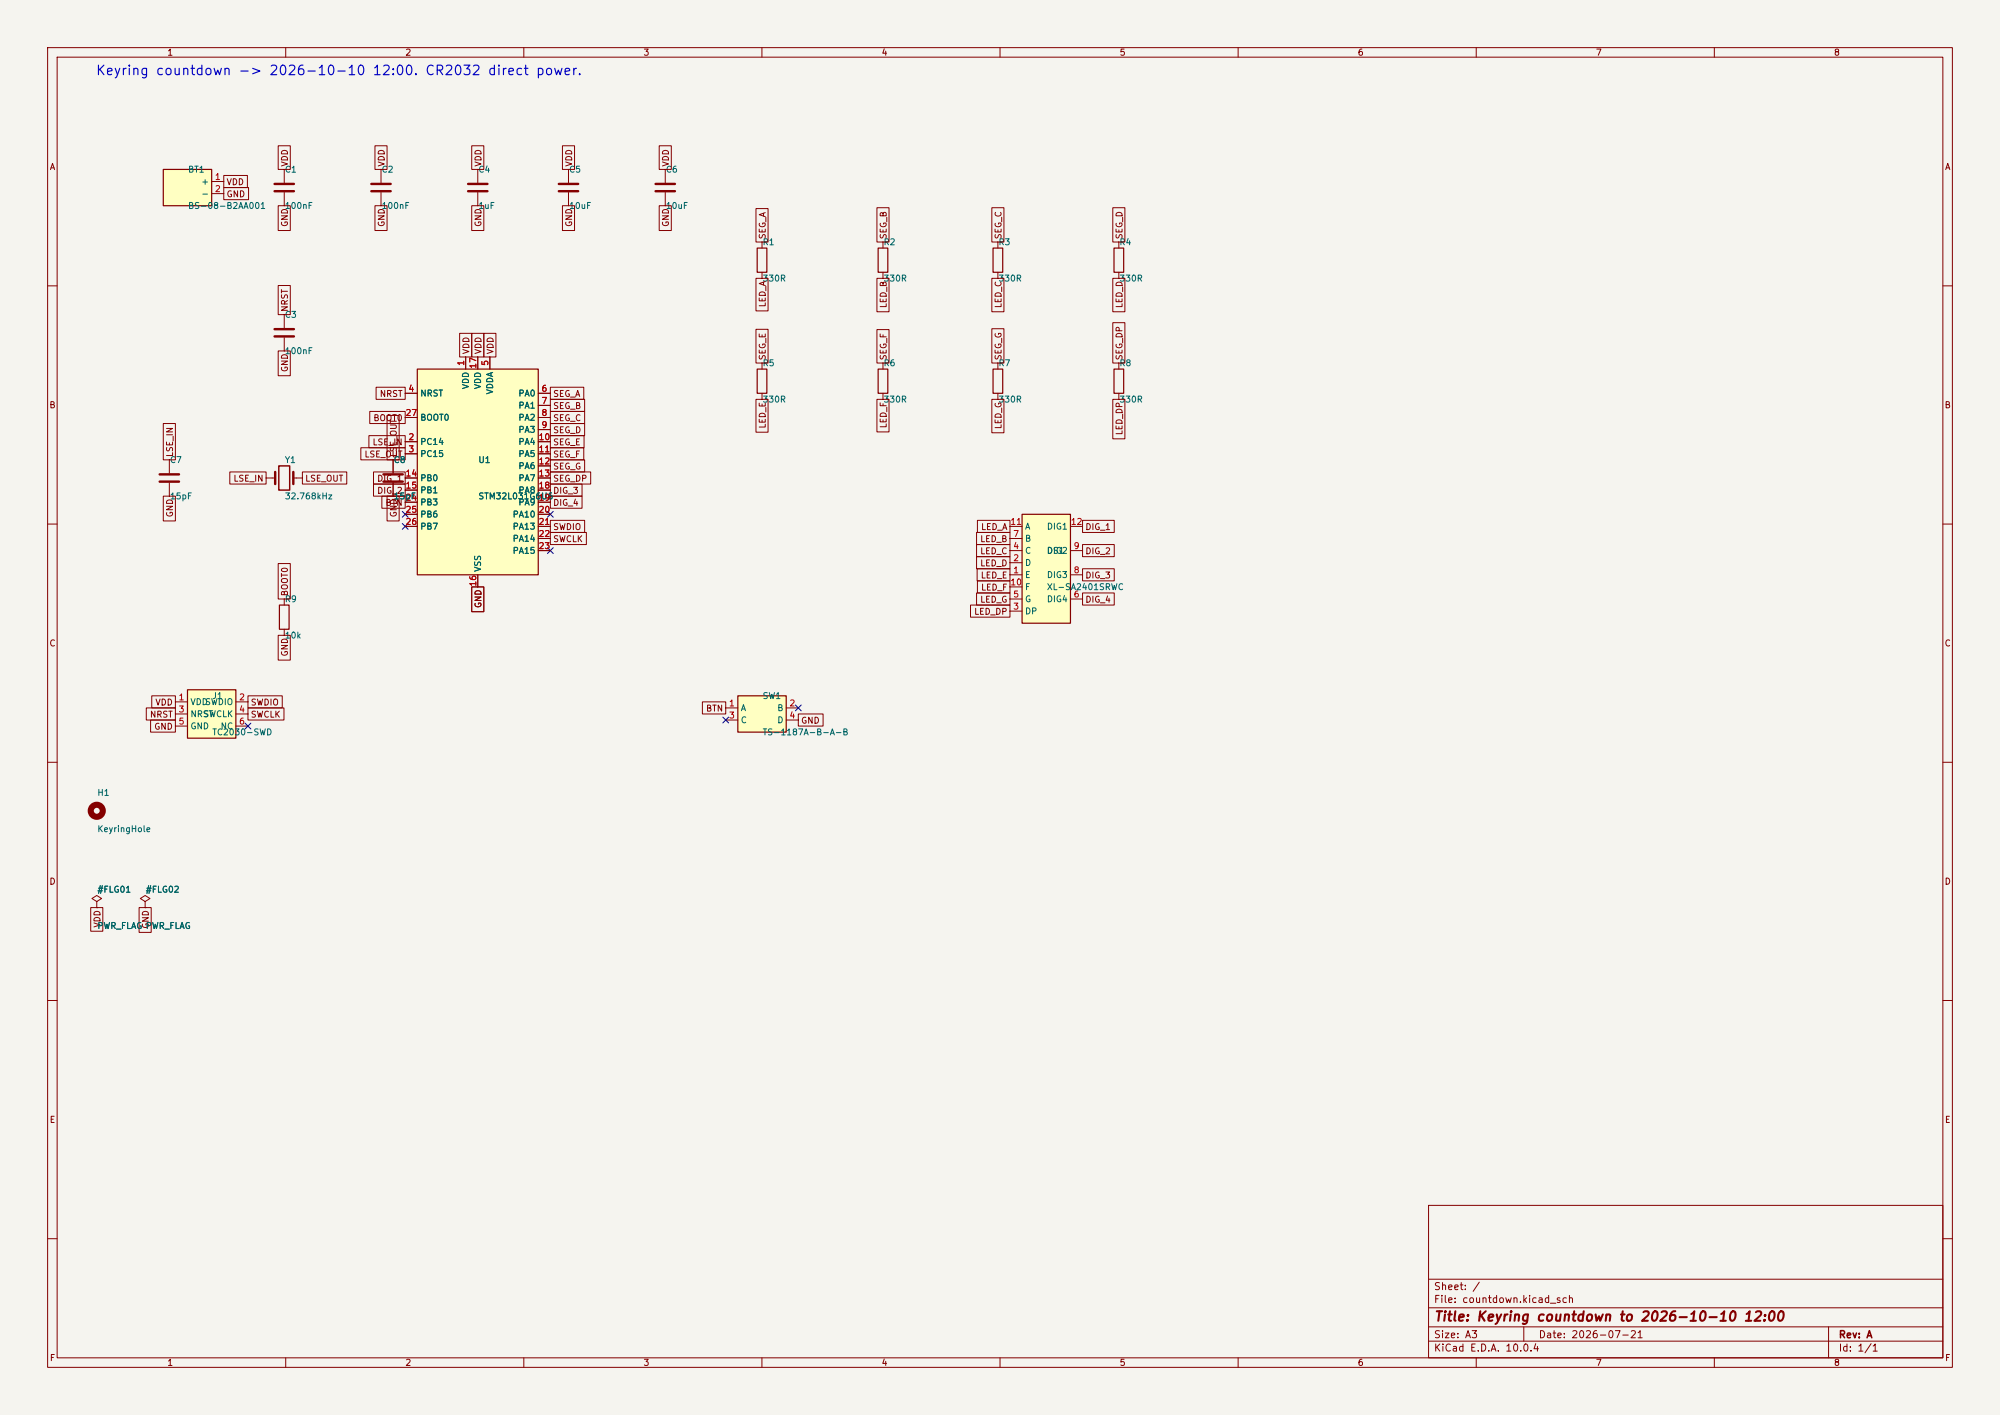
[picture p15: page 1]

Keyring countdown -> 2026-10-10 12:00. CR2032 direct power. U1

1 PC14 2 PC15 3 NRST 4 VDDA 5 PA0 6 PA1 7 PA2 8 PA3 9 PA4 10 PA5 11 PA6 12 PA7 13 PB0 14 PB1 15 VSS 16 VDD 17 PA8 18 PA9 19 PA10 20 PA13 21 PA14 22 PA15 23 PB3 24 PB6 25 PB7 26 BOOT0 27 C8

1 PC14 2 PC15 3 NRST 4 VDDA 5 PA0 6 PA1 7 PA2 8 PA3 9 PA4 10 PA5 11 PA6 12 PA7 13 PB0 14 PB1 15 VSS 16 VDD 17 PA8 18 PA9 19 PA10 20 PA13 21 PA14 22 PA15 23 PB3 24 PB6 25 PB7 26 BOOT0 27 U1

Sheet: /
File: countdown.kicad_sch
Title: Keyring countdown to 2026-10-10 12:00

Size: A3 | Rev: A | F Date: 2026-07-21
KiCad E.D.A. 10.0.4 | Id: 1/1

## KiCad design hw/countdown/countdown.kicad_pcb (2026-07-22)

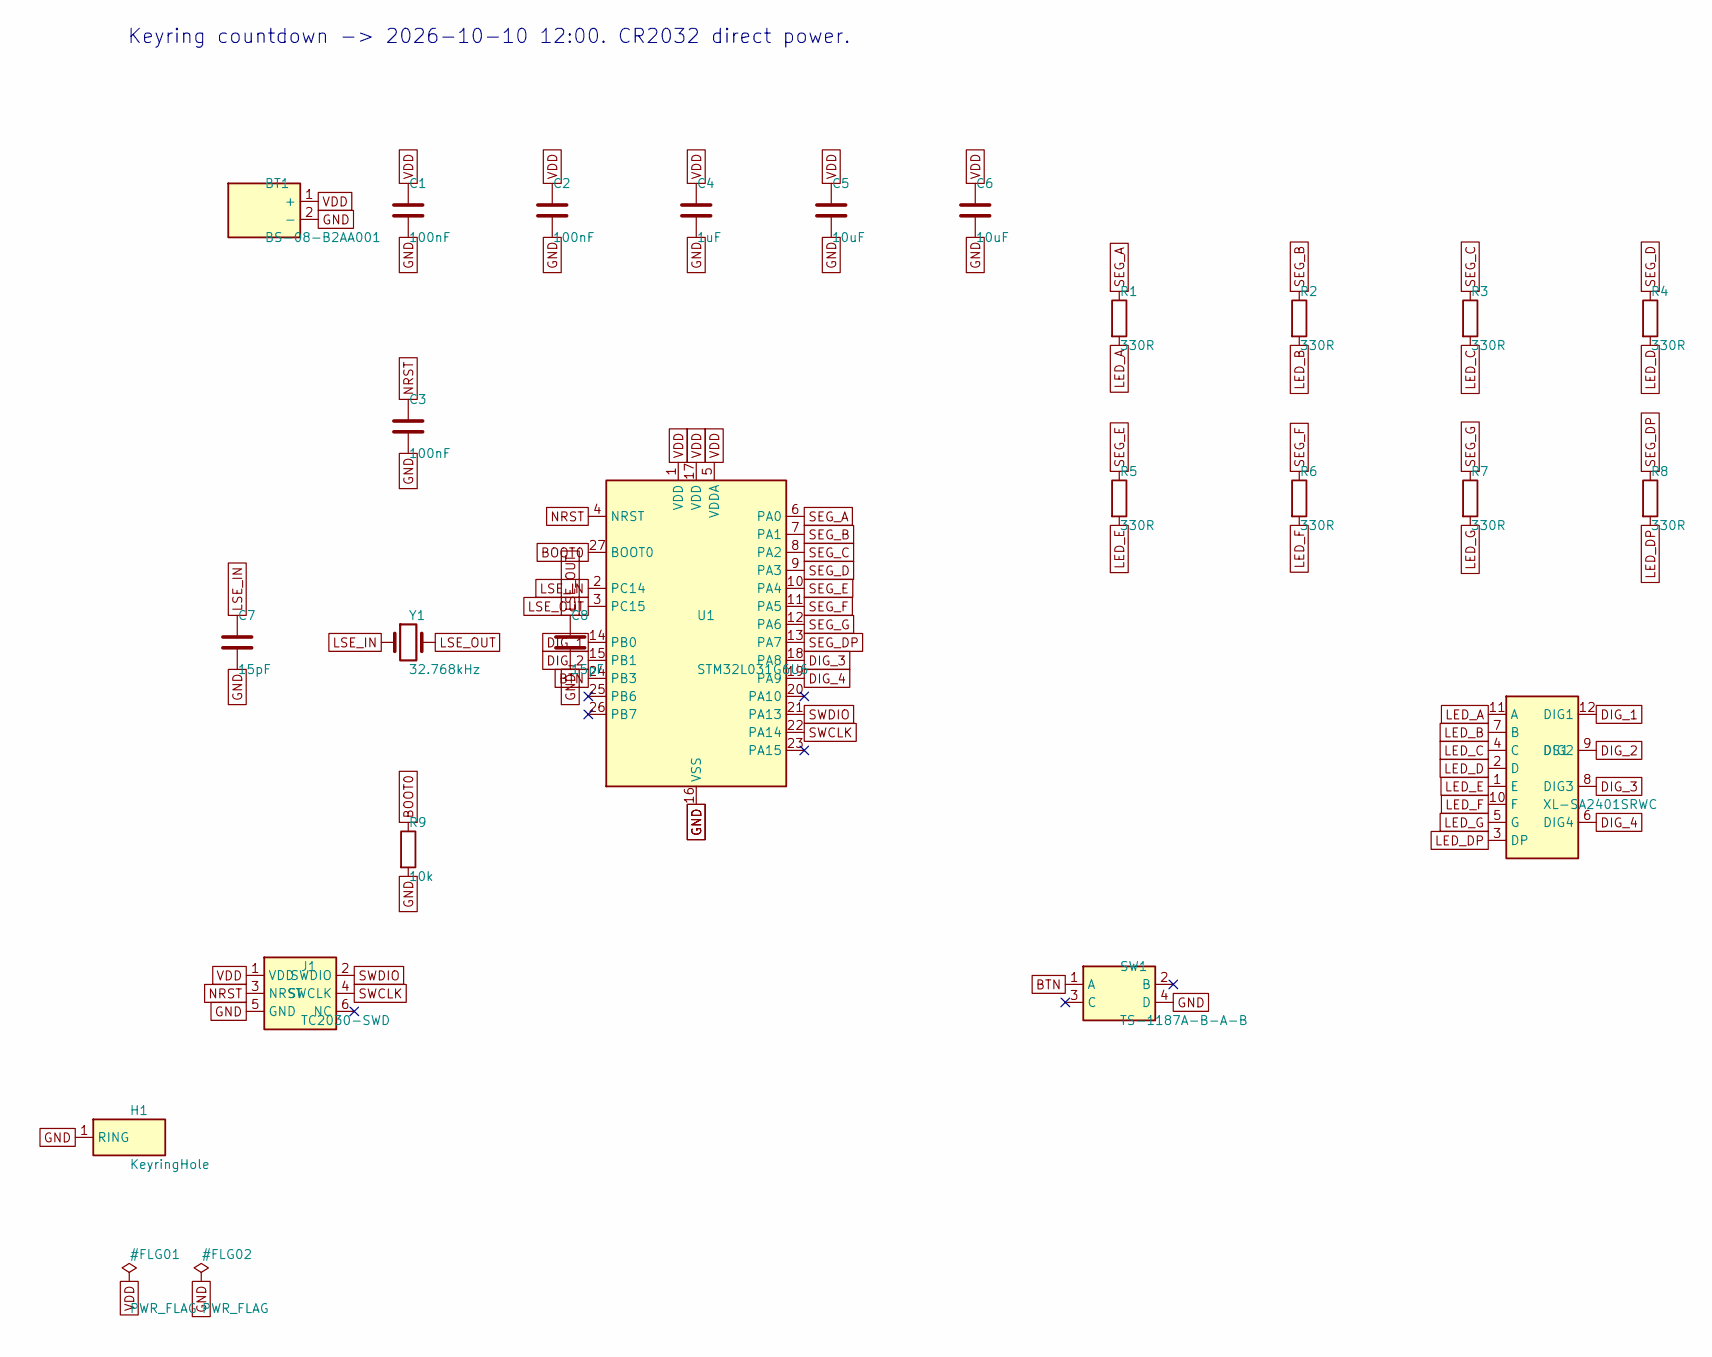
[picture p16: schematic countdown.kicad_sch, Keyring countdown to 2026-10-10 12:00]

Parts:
BT1: BS-08-B2AA001; LCSC C964777
C1, C2, C3: 100nF; C_0603_1608Metric; LCSC C14663
C4: 1uF; C_0603_1608Metric; LCSC C15849
C5, C6: 10uF; C_0603_1608Metric; LCSC C19702
C7, C8: 15pF; C_0603_1608Metric; LCSC C1644
DS1: XL-SA2401SRWC; LCSC C49652871
H1: KeyringHole; KeyringHole_4mm
J1: TC2030-SWD; Tag-Connect_TC2030-IDC-NL_2x03_P1.27mm_Vertical
R1, R2, R3, R4, R5, R6, R7, R8: 330R; R_0603_1608Metric; LCSC C23138
R9: 10k; R_0603_1608Metric; LCSC C25804
SW1: TS-1187A-B-A-B; SW_TS-1187A; LCSC C318884
U1: STM32L031G6U6; QFN-28_4x4mm_P0.5mm; LCSC C96514
Y1: 32.768kHz; Crystal_SMD_3215-2Pin_3.2x1.5mm; LCSC C32346

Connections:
BOOT0: R9.1, U1.27 (BOOT0)
BTN: SW1.1 (A), U1.24 (PB3)
DIG_1: DS1.12 (DIG1), U1.14 (PB0)
DIG_2: DS1.9 (DIG2), U1.15 (PB1)
DIG_3: DS1.8 (DIG3), U1.18 (PA8)
DIG_4: DS1.6 (DIG4), U1.19 (PA9)
GND: BT1.2 (-), C1.2, C2.2, C3.2, C4.2, C5.2, C6.2, C7.2, C8.2, H1.1, J1.5 (GND), R9.2, SW1.4 (D), U1.16 (VSS), U1.28 (VSS)
LED_A: DS1.11 (A), R1.2
LED_B: DS1.7 (B), R2.2
LED_C: DS1.4 (C), R3.2
LED_D: DS1.2 (D), R4.2
LED_DP: DS1.3 (DP), R8.2
LED_E: DS1.1 (E), R5.2
LED_F: DS1.10 (F), R6.2
LED_G: DS1.5 (G), R7.2
LSE_IN: C7.1, U1.2 (PC14), Y1.1
LSE_OUT: C8.1, U1.3 (PC15), Y1.2
NRST: C3.1, J1.3 (NRST), U1.4 (NRST)
SEG_A: R1.1, U1.6 (PA0)
SEG_B: R2.1, U1.7 (PA1)
SEG_C: R3.1, U1.8 (PA2)
SEG_D: R4.1, U1.9 (PA3)
SEG_DP: R8.1, U1.13 (PA7)
SEG_E: R5.1, U1.10 (PA4)
SEG_F: R6.1, U1.11 (PA5)
SEG_G: R7.1, U1.12 (PA6)
SWCLK: J1.4 (SWCLK), U1.22 (PA14)
SWDIO: J1.2 (SWDIO), U1.21 (PA13)
VDD: BT1.1 (+), C1.1, C2.1, C4.1, C5.1, C6.1, J1.1 (VDD), U1.1 (VDD), U1.5 (VDDA), U1.17 (VDD)

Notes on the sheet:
Keyring countdown -> 2026-10-10 12:00. CR2032 direct power.

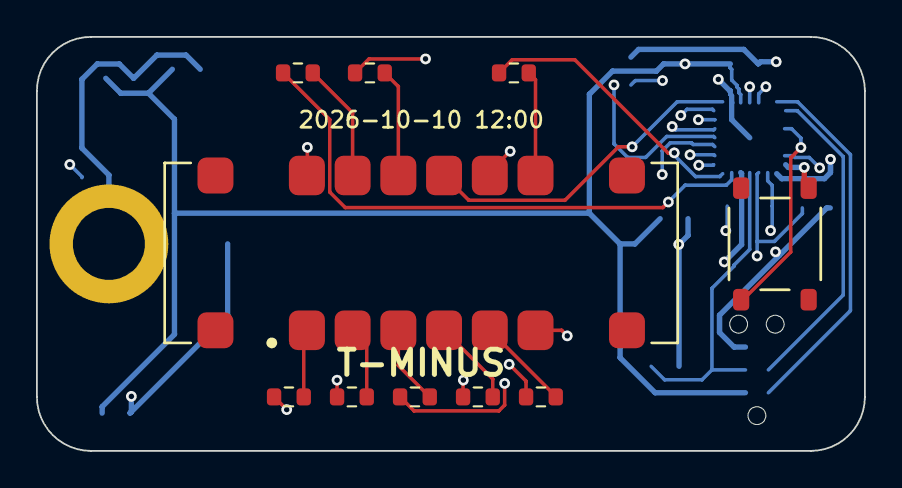
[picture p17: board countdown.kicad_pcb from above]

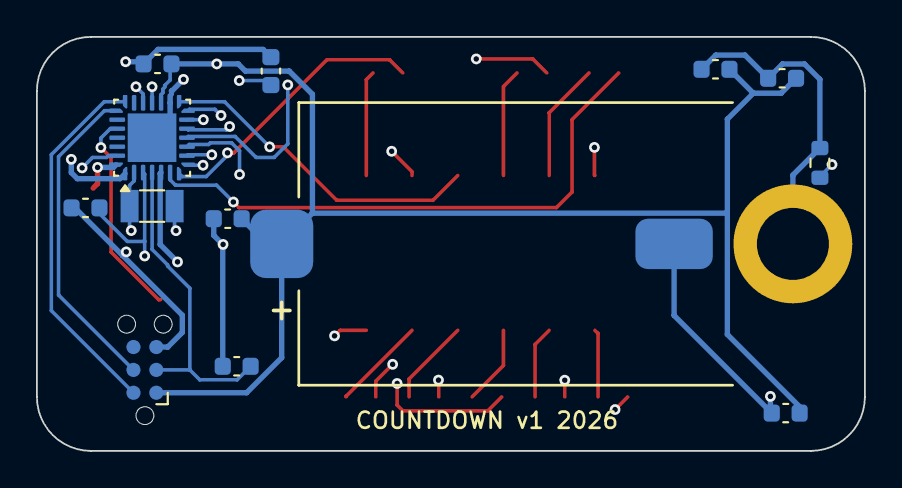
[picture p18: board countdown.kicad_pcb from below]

Board: 4 copper layers, 46.0 x 23.0 mm, 24 parts (13 on the bottom side), 29 nets.

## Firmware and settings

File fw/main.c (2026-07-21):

/* Keyring countdown to 2026-10-10 12:00 — STM32L031G6U6.
 *
 * Behaviour: RTC keeps local time on the 32.768 kHz LSE crystal, MCU sleeps
 * in Stop mode (~1 uA). A button press wakes it; it multiplexes the hours
 * (or, under 100 h, minutes with decimal point lit) remaining until the
 * target onto a 4-digit common-cathode 7-segment display for a few seconds,
 * then returns to Stop. Timekeeping survives everything except battery
 * removal; on first power-up the RTC is seeded with the firmware build
 * timestamp (so flash it right after building).
 */
#include <stdint.h>

#include "stm32l031xx.h"
#include "config.h"

#ifndef BUILD_UNIX_LOCAL
#error "BUILD_UNIX_LOCAL must be passed by the Makefile (local-time epoch)"
#endif

/* ---- tiny civil-calendar helpers (Howard Hinnant's algorithms) ---- */
static int32_t days_from_civil(int32_t y, uint32_t m, uint32_t d)
{
    y -= m <= 2;
    const int32_t era = (y >= 0 ? y : y - 399) / 400;
    const uint32_t yoe = (uint32_t)(y - era * 400);
    const uint32_t doy = (153 * (m + (m > 2 ? -3 : 9)) + 2) / 5 + d - 1;
    const uint32_t doe = yoe * 365 + yoe / 4 - yoe / 100 + doy;
    return era * 146097 + (int32_t)doe - 719468;
}

static void civil_from_days(int32_t z, int32_t *y, uint32_t *m, uint32_t *d)
{
    z += 719468;
    const int32_t era = (z >= 0 ? z : z - 146096) / 146097;
    const uint32_t doe = (uint32_t)(z - era * 146097);
    const uint32_t yoe = (doe - doe / 1460 + doe / 36524 - doe / 146096) / 365;
    int32_t yy = (int32_t)yoe + era * 400;
    const uint32_t doy = doe - (365 * yoe + yoe / 4 - yoe / 100);
    const uint32_t mp = (5 * doy + 2) / 153;
    *d = doy - (153 * mp + 2) / 5 + 1;
    *m = mp + (mp < 10 ? 3 : -9);
    *y = yy + (*m <= 2);
}

/* ---- display tables ---- */
static const uint8_t FONT[10] = {
    /* gfedcba */
    0x3F, 0x06, 0x5B, 0x4F, 0x66, 0x6D, 0x7D, 0x07, 0x7F, 0x6F
};
static const uint8_t SEG_PINS[8] = {
    SEGA_PIN, SEGB_PIN, SEGC_PIN, SEGD_PIN,
    SEGE_PIN, SEGF_PIN, SEGG_PIN, SEGDP_PIN
};
static GPIO_TypeDef *const DIG_PORT[4] = {DIG1_PORT, DIG2_PORT, DIG3_PORT, DIG4_PORT};
static const uint8_t DIG_PIN[4] = {DIG1_PIN, DIG2_PIN, DIG3_PIN, DIG4_PIN};

/* show_frame() writes the segment byte straight to GPIOA pins 0-7 */
_Static_assert(SEGA_PIN == 0 && SEGB_PIN == 1 && SEGC_PIN == 2 &&
               SEGD_PIN == 3 && SEGE_PIN == 4 && SEGF_PIN == 5 &&
               SEGG_PIN == 6 && SEGDP_PIN == 7,
               "show_frame assumes identity segment mapping on PA0-7");

static volatile uint32_t g_ms;

void SysTick_Handler(void) { g_ms++; }

static void delay_ms(uint32_t ms)
{
    uint32_t start = g_ms;
    while ((g_ms - start) < ms)
        __WFI();
}

/* ---- GPIO helpers ---- */
static void gpio_mode(GPIO_TypeDef *g, uint32_t pin, uint32_t mode)
{
    g->MODER = (g->MODER & ~(3u << (pin * 2))) | (mode << (pin * 2));
}

static void display_pins_active(int active)
{
    /* active: segments/digits push-pull outputs; else: analog (Hi-Z, 0 uA) */
    for (int i = 0; i < 8; i++) {
        if (active) {
            GPIOA->BSRR = (1u << (SEG_PINS[i] + 16)); /* low = seg off */
            gpio_mode(GPIOA, SEG_PINS[i], 1);
        } else {
            gpio_mode(GPIOA, SEG_PINS[i], 3);
        }
    }
    for (int i = 0; i < 4; i++) {
        if (active) {
            DIG_PORT[i]->BSRR = (1u << DIG_PIN[i]); /* high = digit off (CC) */
            gpio_mode(DIG_PORT[i], DIG_PIN[i], 1);
        } else {
            gpio_mode(DIG_PORT[i], DIG_PIN[i], 3);
        }
    }
}

/* ---- RTC ---- */
static uint32_t bcd(uint32_t v) { return ((v / 10) << 4) | (v % 10); }
static uint32_t unbcd(uint32_t v) { return (v >> 4) * 10 + (v & 0xF); }

static void rtc_unlock(void)
{
    RTC->WPR = 0xCA;
    RTC->WPR = 0x53;
}

static void error_blink(void)
{
    /* LSE failed: blink segment G of every digit forever (distinct from a
     * flat battery, which shows nothing at all) */
    display_pins_active(1);
    for (;;) {
        for (int d = 0; d < 4; d++)
            DIG_PORT[d]->BSRR = 1u << (DIG_PIN[d] + 16);
        GPIOA->BSRR = 1u << SEGG_PIN;
        delay_ms(300);
        GPIOA->BSRR = 1u << (SEGG_PIN + 16);
        delay_ms(300);
    }
}

static int rtc_did_seed;

static void rtc_init_if_needed(void)
{
    RCC->APB1ENR |= RCC_APB1ENR_PWREN;
    (void)RCC->APB1ENR; /* errata: settle clock enable before next access */
    PWR->CR |= PWR_CR_DBP;

    if ((RTC->ISR & RTC_ISR_INITS) != 0) {
        /* RTC already running (reflash without power loss); still make sure
         * calendar reads bypass the shadow registers (see rtc_now_epoch) */
        rtc_unlock();
        RTC->CR |= RTC_CR_BYPSHAD;
        RTC->WPR = 0xFF;
        return;
    }
    rtc_did_seed = 1;

    /* LSEDRV must be programmed while LSE is off (RM0377), then enable */
    RCC->CSR = (RCC->CSR & ~RCC_CSR_LSEDRV) | RCC_CSR_LSEDRV_1;
    RCC->CSR |= RCC_CSR_LSEON;
    for (uint32_t t = g_ms; !(RCC->CSR & RCC_CSR_LSERDY);)
        if ((g_ms - t) > 4000u)
            error_blink(); /* dead crystal: never returns */
    RCC->CSR = (RCC->CSR & ~RCC_CSR_RTCSEL) | RCC_CSR_RTCSEL_LSE | RCC_CSR_RTCEN;

    rtc_unlock();
    RTC->ISR |= RTC_ISR_INIT;
    while (!(RTC->ISR & RTC_ISR_INITF))
        ;
    /* calendar reads via BYPSHAD + double-read loop (Stop-mode safe) */
    RTC->CR |= RTC_CR_BYPSHAD;
    /* prescalers: reset default 127/255 already gives 1 Hz from 32768 Hz;
     * written anyway, sync then async per RM0377 double-write rule */
    RTC->PRER = 255u;
    RTC->PRER = (127u << 16) | 255u;

    /* seed calendar from build-time local epoch */
    int64_t t = (int64_t)BUILD_UNIX_LOCAL;
    int32_t days = (int32_t)(t / 86400);
    uint32_t sod = (uint32_t)(t % 86400);
    int32_t y;
    uint32_t mo, d;
    civil_from_days(days, &y, &mo, &d);
    /* weekday: epoch day 0 was a Thursday; ((days+3) mod 7)+1 gives Mon=1 */
    uint32_t wd = (uint32_t)(((days + 3) % 7) + 1);
    RTC->TR = (bcd(sod / 3600) << 16) | (bcd((sod / 60) % 60) << 8) | bcd(sod % 60);
    RTC->DR = (bcd((uint32_t)(y - 2000)) << 16) | (wd << 13) |
              (bcd(mo) << 8) | bcd(d);
    RTC->ISR &= ~RTC_ISR_INIT;
    RTC->WPR = 0xFF;
}

static int64_t rtc_now_epoch(void)
{
    /* BYPSHAD=1: read direct calendar registers twice until stable
     * (RM0377-prescribed pattern; immune to Stop-mode shadow staleness) */
    uint32_t ssr, tr, dr;
    do {
        ssr = RTC->SSR;
        tr = RTC->TR;
        dr = RTC->DR;
    } while (RTC->SSR != ssr || RTC->TR != tr);
    (void)ssr;
    int32_t y = 2000 + (int32_t)unbcd((dr >> 16) & 0xFF);
    uint32_t mo = unbcd((dr >> 8) & 0x1F);
    uint32_t d = unbcd(dr & 0x3F);
    uint32_t h = unbcd((tr >> 16) & 0x3F);
    uint32_t mi = unbcd((tr >> 8) & 0x7F);
    uint32_t s = unbcd(tr & 0x7F);
    return (int64_t)days_from_civil(y, mo, d) * 86400 + h * 3600 + mi * 60 + s;
}

/* ---- display one frame (all 4 digits once) ---- */
static void show_frame(const uint8_t segs[4])
{
    for (int d = 0; d < 4; d++) {
        /* set segments for this digit */
        GPIOA->BSRR = (uint32_t)(~segs[d] & 0xFF) << 16 | segs[d];
        /* enable digit (sink low) */
        DIG_PORT[d]->BSRR = 1u << (DIG_PIN[d] + 16);
        delay_ms(DIGIT_DWELL_MS);
        /* digit off, segments off (avoid ghosting) */
        DIG_PORT[d]->BSRR = 1u << DIG_PIN[d];
        GPIOA->BSRR = 0xFFu << 16;
    }
}

static void render_value(uint32_t v, int dp_digit, uint8_t out[4])
{
    for (int i = 3; i >= 0; i--) {
        out[i] = FONT[v % 10];
        v /= 10;
    }
    /* blank leading zeros (keep the last digit) */
    for (int i = 0; i < 3; i++) {
        if (out[i] != FONT[0])
            break;
        out[i] = 0;
    }
    if (dp_digit >= 0)
        out[dp_digit] |= 0x80;
}

static void display_countdown(void)
{
    display_pins_active(1);
    uint32_t start = g_ms;
    while ((g_ms - start) < DISPLAY_ON_MS) {
        int64_t now = rtc_now_epoch();
        int64_t target = (int64_t)days_from_civil(TARGET_Y, TARGET_MO, TARGET_D) * 86400
                         + TARGET_H * 3600 + TARGET_MIN * 60;
        int64_t rem = target - now;
        uint8_t segs[4];
        if (rem <= 0) {
            /* arrived: show 0.0.0.0 solid */
            segs[0] = segs[1] = segs[2] = segs[3] = FONT[0] | 0x80;
        } else {
            int64_t hours = rem / 3600;
            if (hours >= 100) {
                if (hours > 9999)
                    hours = 9999;
                render_value((uint32_t)hours, -1, segs);
            } else {
                /* under 100 h: minutes remaining, DP on digit 1 as marker */
                int64_t mins = rem / 60;
                render_value((uint32_t)mins, 0, segs);
            }
        }
        /* ~30 frames between recomputes */
        for (int f = 0; f < 30; f++)
            show_frame(segs);
    }
    display_pins_active(0);
}

/* ---- button EXTI ---- */
void EXTI2_3_IRQHandler(void)
{
    EXTI->PR = (1u << BTN_PIN); /* clear */
}

static void enter_stop(void)
{
    PWR->CR |= PWR_CR_ULP | PWR_CR_LPSDSR; /* ultra-low-power, regulator LP */
    PWR->CR &= ~PWR_CR_PDDS;               /* Stop, not Standby */
    SCB->SCR |= SCB_SCR_SLEEPDEEP_Msk;
    SysTick->CTRL &= ~SysTick_CTRL_ENABLE_Msk; /* no systick wakes in stop */
    __WFI();
    SysTick->CTRL |= SysTick_CTRL_ENABLE_Msk;
    SCB->SCR &= ~SCB_SCR_SLEEPDEEP_Msk;
}

int main(void)
{
    /* clocks: stay on MSI 2.097 MHz. Enable GPIO + SYSCFG */
    RCC->IOPENR |= RCC_IOPENR_GPIOAEN | RCC_IOPENR_GPIOBEN | RCC_IOPENR_GPIOCEN;
    (void)RCC->IOPENR;
    RCC->APB2ENR |= RCC_APB2ENR_SYSCFGEN;
    (void)RCC->APB2ENR;

    SysTick_Config(2097000 / 1000); /* 1 ms tick */

    /* all unused pins analog to minimise leakage (default after reset is
     * analog on L0 anyway, but be explicit for display pins) */
    display_pins_active(0);

    /* button: input, pull-up, EXTI falling */
    gpio_mode(BTN_PORT, BTN_PIN, 0);
    BTN_PORT->PUPDR = (BTN_PORT->PUPDR & ~(3u << (BTN_PIN * 2))) | (1u << (BTN_PIN * 2));
    SYSCFG->EXTICR[BTN_PIN / 4] &= ~(0xFu << ((BTN_PIN % 4) * 4));
    SYSCFG->EXTICR[BTN_PIN / 4] |= (0x1u << ((BTN_PIN % 4) * 4)); /* port B */
    EXTI->FTSR |= (1u << BTN_PIN);
    EXTI->IMR |= (1u << BTN_PIN);
    NVIC_EnableIRQ(EXTI2_3_IRQn);

    rtc_init_if_needed();

    if (rtc_did_seed) {
        /* signal "clock (re)seeded from the firmware build timestamp":
         * all four decimal points flash three times. If you see this after
         * a battery swap WITHOUT having just flashed fresh firmware, the
         * countdown is stale - rebuild and reflash. */
        display_pins_active(1);
        for (int k = 0; k < 3; k++) {
            uint8_t dots[4] = {0x80, 0x80, 0x80, 0x80};
            uint32_t t0 = g_ms;
            while ((g_ms - t0) < 220u)
                show_frame(dots);
            display_pins_active(1); /* keep outputs, clear segments */
            delay_ms(160);
        }
    }

    /* greet: show countdown once at power-up */
    display_countdown();

    for (;;) {
        enter_stop();
        /* woken by button */
        display_countdown();
        /* if the button is stuck/held (pocket squeeze), wait for release so
         * we don't re-light the display forever */
        while (!(BTN_PORT->IDR & (1u << BTN_PIN)))
            delay_ms(50);
    }
}

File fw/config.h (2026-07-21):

#pragma once
/* Countdown target: 2026-10-10 12:00:00 LOCAL time.
 * The RTC runs in local time, set at flash time from the build timestamp
 * (see Makefile: BUILD_LOCAL_* macros). Both flash date (summer 2026) and
 * the target fall inside British Summer Time (ends 25 Oct 2026), so local
 * time has no DST discontinuity before the target. */
#define TARGET_Y 2026
#define TARGET_MO 10
#define TARGET_D 10
#define TARGET_H 12
#define TARGET_MIN 0

/* How long the display stays on after a button press (ms) */
#define DISPLAY_ON_MS 8000u
/* Per-digit dwell during multiplexing (ms): 4 digits -> ~125 Hz frame */
#define DIGIT_DWELL_MS 2u

/* --- Pin map (matches hw/scripts/gen_sch.py — single source of truth is
 * the PINMAP table in that file; keep in sync, checked by review) ---
 * Segments A..G,DP drive GPIOA pins SEG_PINS[i] (source current, active high
 * for common-cathode display).
 * Digits 1..4 sink through DIG_PORT/DIG_PIN (active low output).
 * Button: PB3 to GND, internal pull-up, EXTI3 falling edge.
 */
#define SEGA_PIN 0 /* PA0 */
#define SEGB_PIN 1 /* PA1 */
#define SEGC_PIN 2 /* PA2 */
#define SEGD_PIN 3 /* PA3 */
#define SEGE_PIN 4 /* PA4 */
#define SEGF_PIN 5 /* PA5 */
#define SEGG_PIN 6 /* PA6 */
#define SEGDP_PIN 7 /* PA7 */

/* digit commons: entries are (GPIO, pin). Digit 1 = leftmost. */
#define DIG1_PORT GPIOB
#define DIG1_PIN 0
#define DIG2_PORT GPIOB
#define DIG2_PIN 1
#define DIG3_PORT GPIOA
#define DIG3_PIN 8
#define DIG4_PORT GPIOA
#define DIG4_PIN 9

#define BTN_PORT GPIOB
#define BTN_PIN 3

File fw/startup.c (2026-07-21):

/* Minimal startup for STM32L031 (Cortex-M0+), no vendor startup needed. */
#include <stdint.h>

extern uint32_t _sidata, _sdata, _edata, _sbss, _ebss, _estack;

int main(void);
void SysTick_Handler(void);
void EXTI2_3_IRQHandler(void);

void Reset_Handler(void)
{
    uint32_t *src = &_sidata, *dst = &_sdata;
    while (dst < &_edata)
        *dst++ = *src++;
    for (dst = &_sbss; dst < &_ebss;)
        *dst++ = 0;
    main();
    for (;;)
        ;
}

void Default_Handler(void)
{
    for (;;)
        ;
}

#define WEAK_DEFAULT __attribute__((weak, alias("Default_Handler")))
void NMI_Handler(void) WEAK_DEFAULT;
void HardFault_Handler(void) WEAK_DEFAULT;
void SVC_Handler(void) WEAK_DEFAULT;
void PendSV_Handler(void) WEAK_DEFAULT;

__attribute__((section(".isr_vector"), used))
const void *const g_vectors[48] = {
    &_estack,
    Reset_Handler,
    NMI_Handler,
    HardFault_Handler,
    0, 0, 0, 0, 0, 0, 0,
    SVC_Handler,
    0, 0,
    PendSV_Handler,
    SysTick_Handler,
    /* IRQ vector numbering per stm32l031xx.h (every slot armed) */
    Default_Handler,      /* 0 WWDG */
    Default_Handler,      /* 1 PVD */
    Default_Handler,      /* 2 RTC */
    Default_Handler,      /* 3 FLASH */
    Default_Handler,      /* 4 RCC */
    Default_Handler,      /* 5 EXTI0_1 */
    EXTI2_3_IRQHandler,   /* 6 EXTI2_3 */
    Default_Handler,      /* 7 EXTI4_15 */
    Default_Handler,      /* 8 reserved */
    Default_Handler,      /* 9 DMA1_Channel1 */
    Default_Handler,      /* 10 DMA1_Channel2_3 */
    Default_Handler,      /* 11 DMA1_Channel4_5_6_7 */
    Default_Handler,      /* 12 ADC_COMP */
    Default_Handler,      /* 13 LPTIM1 */
    Default_Handler,      /* 14 USART4_5 (n/a on L031) */
    Default_Handler,      /* 15 TIM2 */
    Default_Handler,      /* 16 TIM3 (n/a) */
    Default_Handler,      /* 17 TIM6 (n/a) */
    Default_Handler,      /* 18 TIM7 (n/a) */
    Default_Handler,      /* 19 reserved */
    Default_Handler,      /* 20 TIM21 */
    Default_Handler,      /* 21 I2C3 (n/a) */
    Default_Handler,      /* 22 TIM22 */
    Default_Handler,      /* 23 I2C1 */
    Default_Handler,      /* 24 I2C2 (n/a) */
    Default_Handler,      /* 25 SPI1 */
    Default_Handler,      /* 26 SPI2 (n/a) */
    Default_Handler,      /* 27 USART1 (n/a) */
    Default_Handler,      /* 28 USART2 */
    Default_Handler,      /* 29 LPUART1 */
    Default_Handler,      /* 30 reserved */
    Default_Handler       /* 31 reserved */
};

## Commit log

2026-07-21 Schematic generation + netlist verification tooling (ERC/netlist pipeline proven on test circuit)
    Claude-Session: https://claude.ai/code/session_01EyK7WVGPpPEnSjWLWWV8on
2026-07-21 Part selection complete: STM32L031+XL-SA2401 display; firmware compiles
    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
2026-07-21 Schematic complete: 0 ERC violations, netlist verified against intent (29 nets/83 nodes)
    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
    [countdown.kicad_sch]
2026-07-21 PCB placement complete: 44x22mm 4-layer, 0 DRC violations pre-route
    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
    [countdown.dsn, countdown.kicad_pcb]
2026-07-21 Routing infrastructure: plain-DSN freerouting flow + deterministic 4-layer repair router
    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
    [countdown.dsn, countdown.kicad_pcb]
2026-07-21 Freerouting-free routing flow (A* with power-first fanout), firmware cleanup, JLC rotation research
    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
    [countdown.kicad_pcb, countdown_i.dsn, countdown_p.dsn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]
2026-07-21 README + JLCPCB ordering guide
    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
    [countdown.kicad_pcb]
2026-07-21 Design log: routing endgame narrative
    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
    [countdown.kicad_pcb]
2026-07-21 Prompt log updates
    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
    [countdown.kicad_pcb]
2026-07-21 Review fixes (fw: BYPSHAD, LSEDRV order, flash staleness, vectors; sch: diagonal switch wiring) + routing endgame tooling
    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
    [countdown.dsn, countdown.kicad_pcb, countdown.kicad_sch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]
2026-07-21 Design log review outcomes; ordering doc updates
    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
    [countdown.kicad_pcb, stage2.dsn, stage2_raw.dsn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]
2026-07-22 Footprint/DFM review fixes: GND-only vias under QFN, via spacing gates, plated GND keyring ring, display pads to true terminal width, silk cleanup + hidden refs
    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
    [countdown.dsn, countdown.kicad_pcb, countdown.kicad_sch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]
2026-07-22 Prompt log: footprint review; fab export zips gerbers
    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
    [countdown.kicad_pcb, stage2.dsn, stage2_raw.dsn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]
2026-07-22 Pure-A* routing flow with QFN-first ordering; EP GND pad; edge-track deletion fix
    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
    [a.dsn, a_p.dsn, base.kicad_pcb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]
2026-07-22 BOARD ROUTED CLEAN: 0 DRC violations, 0 unconnected, 0 parity issues, 0 gate failures (U1 rot90 placement + seed-32 + A* close-out)
    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
    [countdown.dsn, countdown.kicad_pcb, frozen.kicad_pcb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]
2026-07-22 Fab outputs: gerbers (split PTH/NPTH), BOM, CPL; renders; final design log
    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
    [bom.csv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]
2026-07-22 Morning stock re-check: all 11 parts in stock, display CC confirmed — ORDER-READY
    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
2026-07-22 3D part models (text-to-cad CAD skill, build123d -> STEP) attached to board + footprint lib; model-populated renders
    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
    [bs08_holder.step, countdown.kicad_pcb, cr2032.step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]
2026-07-22 README: correct board dimensions
    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
2026-07-22 Potting tooling: both-sides encapsulation mold + TPU button plug (text-to-cad CAD skill, geometrically probe-verified), process doc
    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
    [pot_button_plug.step, pot_button_plug.stl, pot_mold.step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]
